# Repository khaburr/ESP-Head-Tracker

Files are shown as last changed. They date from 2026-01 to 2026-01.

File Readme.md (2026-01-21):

This is a simple project that I've created just to solve a problem, and I used whatever I had at hand. 
It will only send Yaw Roll and Pitch, since there's no way to "know" the translation!

I'm no programmer so the code is as it is, but it works well for me. For orientation calculation I used sensor fusion algorithm developed by jremington. Big thanks for sharing the implementation of the Mahony filters for MPU-6050. For comunication with the MPU6050 I use FastIMU. Inside the box I have Seeed studio Xiao esp32-c3, mpu6050, small battery form old e-cig (suprised it still works), and 21x15mm Rocker Switch. If i wanted to make MK II of the box i would fix the switch cutout, and make the lid a litte longer, so it will acually snap together.

To configure it, download FastIMU lubrary from Arduino, set network name, network password, and target PC ip address. Make sure correct pins for MPU6050 are set and switch on device, let it sit flat for about 5 seconds, and open Opentrack with Input set to FreePIE UDP reciver. I've created drift compensation brackets that assume that most of the time you are facing the monitor, it works good for DCS. In my design i used pins 9 and 10 for sda and scl, since in ESP you can use i2c on any pins.

For soldering this device together you can create matrix by just printing bottom few milimiters of the box. I did this unintentionally as my print failed, but it created neat cable management.

There is no license to this, feel free to use it however you want.

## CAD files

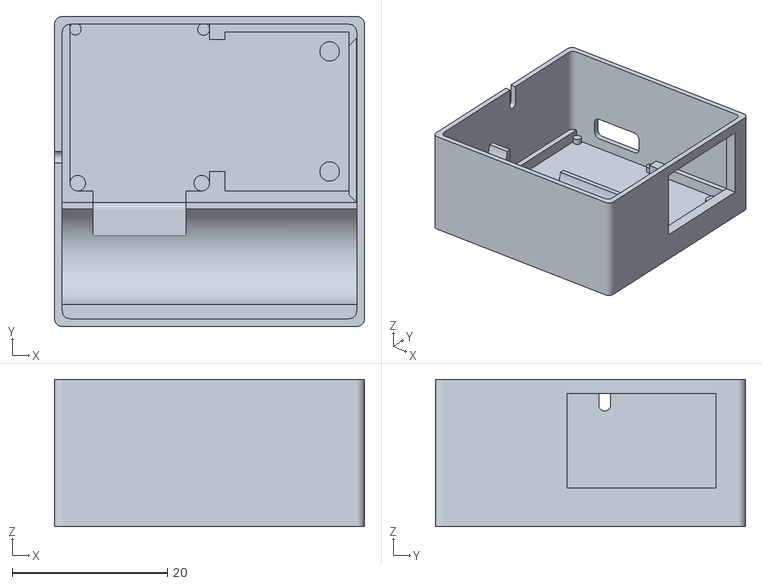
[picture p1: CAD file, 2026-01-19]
Box_main.stl
40.0 x 40.0 x 19.0

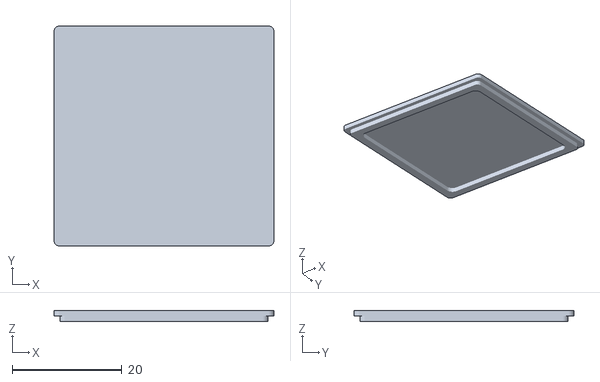
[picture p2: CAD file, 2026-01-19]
Box_lid.stl
40.0 x 40.0 x 2.00

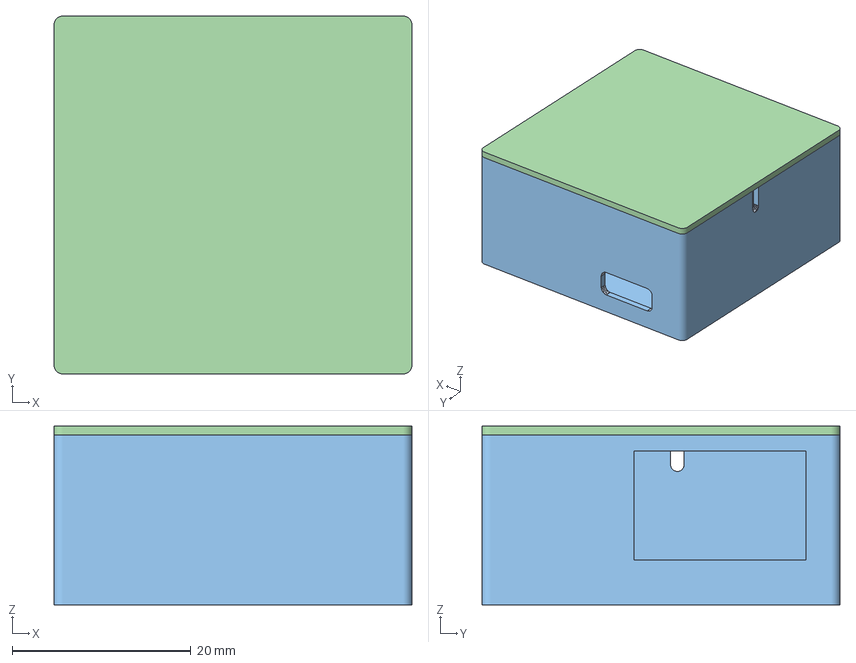
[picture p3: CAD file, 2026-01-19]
box.FCStd
40.0 x 40.0 x 20.0 mm
Box_main
Box_lid

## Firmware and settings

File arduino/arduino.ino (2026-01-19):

// Calculations based on MPU-6050-Fusion by jremington
// Original source: https://github.com/jremington/MPU-6050-Fusion

#include "FastIMU.h"
#include <WiFi.h>
#include <WiFiUdp.h>
#include <Wire.h>

#define IMU_ADDRESS 0x68
#define I2C_SDA 9
#define I2C_SCL 10

// Network connection
const char* ssid = "YourSSID";
const char* password = "YourPassword";
const char* pcIP = "192.168.1.XX"; // local IP adress of the PCM to send packets to
const int port = 5555; // Port that will listen to UDP - 5555 by default

calData calib = { 0 }; // Calibration data
AccelData accelData; // Sensor data
GyroData gyroData;

MPU6050 IMU;
WiFiUDP udp;

// GLOBALLY DECLARED, required for Mahony filter
// vector to hold quaternion
float q[4] = { 1.0, 0.0, 0.0, 0.0 };

// Free parameters in the Mahony filter and fusion scheme,
// Kp for proportional feedback, Ki for integral
float Kp = 20.0;
float Ki = 0.0;

// globals for AHRS loop timing
unsigned long last_ms = 0; // millis() timers
float yaw, pitch, roll, yaw_rad, pitch_rad, roll_rad; // Euler angle output
float yaw_offset = 0.0; // Drift correction variable

void setup()
{

    Wire.begin(I2C_SDA, I2C_SCL);
    Wire.setClock(400000); // 400khz clock
    Serial.begin(115200);

    int err = IMU.init(calib, IMU_ADDRESS);
    if (err != 0) {
        Serial.print("Error initializing IMU: ");
        Serial.println(err);
        while (true) {
            ;
        }
    }

    Serial.println("Keep IMU level.");
    IMU.calibrateAccelGyro(&calib);
    Serial.println("Calibration done!");
    Serial.println("Accel biases X/Y/Z: ");
    Serial.print(calib.accelBias[0]);
    Serial.print(", ");
    Serial.print(calib.accelBias[1]);
    Serial.print(", ");
    Serial.println(calib.accelBias[2]);
    Serial.println("Gyro biases X/Y/Z: ");
    Serial.print(calib.gyroBias[0]);
    Serial.print(", ");
    Serial.print(calib.gyroBias[1]);
    Serial.print(", ");
    Serial.println(calib.gyroBias[2]);

    IMU.init(calib, IMU_ADDRESS);

    err = IMU.setGyroRange(500); // USE THESE TO SET THE RANGE, IF AN INVALID RANGE IS SET IT WILL RETURN -1
    err = IMU.setAccelRange(2); // THESE TWO SET THE GYRO RANGE TO ±500 DPS AND THE ACCELEROMETER RANGE TO ±2g

    if (err != 0) {
        Serial.print("Error Setting range: ");
        Serial.println(err);
        while (true) {
            ;
        }
    }

    delay(3000);
    WiFi.begin(ssid, password);
    WiFi.setSleep(false);

    while (WiFi.status() != WL_CONNECTED) {
        delay(1000);
        Serial.println("Standby - connecting");
        Serial.println(WiFi.status());
    }
    udp.begin(port);
    Serial.println("Connected");
}

void loop()
{

    static float deltat = 0; // loop time in seconds
    static unsigned long now = 0, last = 0; // micros() timers

    if (WiFi.status() != WL_CONNECTED) {
        Serial.println("WiFi lost! Reconnecting...");
        WiFi.disconnect();
        WiFi.begin(ssid, password);
        return;
    }

    // raw data
    int16_t ax, ay, az;
    int16_t gx, gy, gz;
    int16_t Tmp; // temperature

    // scaled data as vector
    float Axyz[3];
    float Gxyz[3];

    IMU.update();
    IMU.getAccel(&accelData);
    IMU.getGyro(&gyroData);

    Axyz[0] = accelData.accelX;
    Axyz[1] = accelData.accelY;
    Axyz[2] = accelData.accelZ;

    Gxyz[0] = (gyroData.gyroX) * 3.14 / 180.0; // 250 LSB(d/s) default to radians/s
    Gxyz[1] = (gyroData.gyroY) * 3.14 / 180.0;
    Gxyz[2] = (gyroData.gyroZ) * 3.14 / 180.0;

    now = micros();
    deltat = (now - last) * 1.0e-6; // seconds since last update
    last = now;

    Mahony_update(Axyz[0], Axyz[1], Axyz[2], Gxyz[0], Gxyz[1], Gxyz[2], deltat);

    roll = atan2((q[0] * q[1] + q[2] * q[3]), 0.5 - (q[1] * q[1] + q[2] * q[2]));
    pitch = asin(2.0 * (q[0] * q[2] - q[1] * q[3]));
    // conventional yaw increases clockwise from North. Not that the MPU-6050 knows where North is.
    yaw = -atan2((q[1] * q[2] + q[0] * q[3]), 0.5 - (q[2] * q[2] + q[3] * q[3]));
    // to degrees
    yaw *= 180.0 / PI;
    if (yaw < 0)
        yaw += 360.0; // compass circle
    pitch *= 180.0 / PI;
    roll *= 180.0 / PI;

    // DRIFT COMPENSATION - I did not use magnetometer, but since you will be mostly facing monitor head on, I've created a brackets for dfift compensation based on that. Works good for me.
    float current_view_yaw = yaw - yaw_offset;
    // normalisation
    if (current_view_yaw > 180.0)
        current_view_yaw -= 360.0;
    if (current_view_yaw < -180.0)
        current_view_yaw += 360.0;

    float drift_step = 0.0;

    if (current_view_yaw <= 7 && current_view_yaw >= -7) {
        drift_step = 1 * deltat; /// factor of drift compensation
    } else if (current_view_yaw > 7 && current_view_yaw <= 15 || current_view_yaw < -7 && current_view_yaw >= -15) {
        drift_step = 0.7 * deltat;
    } else if (current_view_yaw > 15 && current_view_yaw < 30 || current_view_yaw < -15 && current_view_yaw > -30) {
        drift_step = 0.5 * deltat;
    }

    if (current_view_yaw > drift_step) {
        yaw_offset += drift_step;
    } else if (current_view_yaw < -drift_step) {
        yaw_offset -= drift_step;
    } else {
        yaw_offset = yaw;
    }

    yaw = current_view_yaw;

    if (yaw < 0)
        yaw += 360.0;

    // print angles for serial plotter...
    Serial.print(yaw, 0);
    Serial.print(", ");
    Serial.print(pitch, 0);
    Serial.print(", ");
    Serial.println(roll, 0);

    yaw_rad = yaw * 3.14 / 180.0; // Angle to radians for OpenTrack
    pitch_rad = pitch * 3.14 / 180.0;
    roll_rad = roll * 3.14 / 180.0;

    uint8_t tinyPacket[14]; // Header of UDP packet
    tinyPacket[0] = 0x00;
    tinyPacket[1] = 0x02;

    packFloat(tinyPacket, 2, yaw_rad); // UDP data packet
    packFloat(tinyPacket, 6, pitch_rad);
    packFloat(tinyPacket, 10, roll_rad);

    if (udp.beginPacket(pcIP, port)) {
        udp.write(tinyPacket, 14);
        if (!udp.endPacket()) {
            Serial.println("UDP Send Error");
        }
    } else {
        Serial.println("UDP Begin Error");
    }

    delay(5);
}

// Based on MPU-6050-Fusion by jremington
// Original source: https://github.com/jremington/MPU-6050-Fusion

void Mahony_update(float ax, float ay, float az, float gx, float gy, float gz, float deltat)
{
    float recipNorm;
    float vx, vy, vz;
    float ex, ey, ez; // error terms
    float qa, qb, qc;
    static float ix = 0.0, iy = 0.0, iz = 0.0; // integral feedback terms
    float tmp;

    // Compute feedback only if accelerometer measurement valid (avoids NaN in accelerometer normalisation)
    tmp = ax * ax + ay * ay + az * az;
    if (tmp > 0.0) {

        // Normalise accelerometer (assumed to measure the direction of gravity in body frame)
        recipNorm = 1.0 / sqrt(tmp);
        ax *= recipNorm;
        ay *= recipNorm;
        az *= recipNorm;

        // Estimated direction of gravity in the body frame (factor of two divided out)
        vx = q[1] * q[3] - q[0] * q[2]; // to normalize these terms, multiply each by 2.0
        vy = q[0] * q[1] + q[2] * q[3];
        vz = q[0] * q[0] - 0.5f + q[3] * q[3];

        // Error is cross product between estimated and measured direction of gravity in body frame
        // (half the actual magnitude)
        ex = (ay * vz - az * vy);
        ey = (az * vx - ax * vz);
        ez = (ax * vy - ay * vx);

        // Compute and apply to gyro term the integral feedback, if enabled
        if (Ki > 0.0f) {
            ix += Ki * ex * deltat; // integral error a pomocnicza do pakowania floatów (scaled by Ki
            iy += Ki * ey * deltat;
            iz += Ki * ez * deltat;
            gx += ix; // apply integral feedback
            gy += iy;
            gz += iz;
        }

        // Apply proportional feedback to gyro term
        gx += Kp * ex;
        gy += Kp * ey;
        gz += Kp * ez;
    }

    // Integrate rate of change of quaternion, q cross gyro term
    deltat = 0.5 * deltat;
    gx *= deltat; // pre-multiply common factors
    gy *= deltat;
    gz *= deltat;
    qa = q[0];
    qb = q[1];
    qc = q[2];
    q[0] += (-qb * gx - qc * gy - q[3] * gz);
    q[1] += (qa * gx + qc * gz - q[3] * gy);
    q[2] += (qa * gy - qb * gz + q[3] * gx);
    q[3] += (qa * gz + qb * gy - qc * gx);

    // renormalise quaternion
    recipNorm = 1.0 / sqrt(q[0] * q[0] + q[1] * q[1] + q[2] * q[2] + q[3] * q[3]);
    q[0] = q[0] * recipNorm;
    q[1] = q[1] * recipNorm;
    q[2] = q[2] * recipNorm;
    q[3] = q[3] * recipNorm;
}

// Function for Little-Endian
void packFloat(uint8_t* buf, int offset, float value)
{
    union {
        float f;
        uint8_t b[4];
    } data;
    data.f = value;
    // Format Little-Endian
    buf[offset] = data.b[0];
    buf[offset + 1] = data.b[1];
    buf[offset + 2] = data.b[2];
    buf[offset + 3] = data.b[3];
}
